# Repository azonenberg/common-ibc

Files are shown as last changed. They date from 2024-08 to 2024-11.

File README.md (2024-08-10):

# common-ibc

This is a 48-12V 72W non-isolated intermediate bus converter which I plan to use in all of my larger FPGA projects.

It uses a charge pump which has a fixed divide-by-4 output ratio rather than using a regulating buck topology. This
allows high efficiency but requires downstream loads to be able to tolerate a wider range of input voltages.

The architecture is scalable to 2 or 4 parallel converter modules, allowing 144W (12A) or 288W (24A) IBCs based on the
same chipset to be constructed in a straightforward manner based on a scaling of this design, however there are no
near-term plans to create such a converter since none of my near term project plans require that much power.

## Input

The input is +48VDC nominal on a 6-pin Molex Mini-Fit Jr connector, using a pinout compatible with the Mean Well
GST280A48-C6P power brick (and possibly others). The negative terminal of the input power connection is connected to
circuit ground.

The permissible operating range is 40 to 56VDC (corresponding to 10 to 14V output). An input protection circuit will
disable the converter if the input is out of this range.

The unregulated output voltage is 1/4 of the input, so if the load has tighter requirements for accuracy of the 12V
rail then this will further constrain the input supply voltage.

## Internal Construction

The converter is built around the Murata MYC0409-NA charge pump DC-DC module.

## Outputs

In addition to the high current 12V output (on an 8-pin Molex Mini-Fit Jr connector) the converter provides a 3.3V
standby rail (using the Cyntec MUN12AD03-SE regulating off of the 12V rail), capable of up to 3A, which is intended for
powering sleep/idle circuitry such as soft power on/off, rail sequencing, etc.

Both the primary 12V step-down converter and the 3.3V standby regulator are always enabled, however a load switch on
the main 12V output allows it to be disabled to completely power down the bulk of the downstream device, keeping only
the converter board and the 3V3_SB rail on the downstream device energized. The load switch has an integrated soft
start, preventing high current surges when charging bulk capacitance on the load.

## Monitoring

The onboard STM32L431 microcontroller monitors the PGOOD signals of internal regulators as well as the ALERT output
of the onboard AT30TS74 temperature sensor. It also continually uses an internal ADC to record the input and output
voltage, downstream load sense voltage, and input and output current. All of these sensor readings may be queried by
the load over the I2C management bus.

## Protection

The converter includes multiple levels of protection to minimize the risk of fire or equipment damage.

The most critical interlocks are implemented in hardware while additional protections with lower thresholds are
implemented in software on the management MCU.

If a software interlock triggers, the 12V output is disabled. The management MCU will automatically attempt to restart
the output (as long as the load is still requesting power) at periodic intervals once the fault condition is cleared.

The 3.3V standby output will remain active and the management MCU will remain operational while a software interlock is
tripped.

### Input overcurrent

The 48V input is fused at 2.5A using a socketed 5x20mm fast-blow fuse.

### Output overcurrent

The 12V primary output is fused at 10A using a soldered-down fast-blow fuse.

The 3.3V standby output is current limited (typical range 3.8 - 5.2A) by the DC-DC converter and does not have an
supplemental fuse.

If the 12V output current exceeds 6.5A, a software interlock is triggered. The output load switch also has a
short circuit protection feature, however the software interlock is intended to trip at a lower level.

### Regulator fault

If any of the internal regulators indicates a problem (PGOOD low) a software interlock is triggered.

### Over-temperature

If the AT30TS74 indicates an out-of-bounds temperature (ALERT low) a software interlock is triggered.

The MCU does not configure the AT30TS74; on power up the default over-temperature limit (80C) is active. This sensor is
located on the same I2C management bus as the MCU and may be reconfigured or queried by the load as required; the
IBC will activate the interlock if the programmed temperature range is exceeded.

### Input under / over voltage

The input is monitored by a TPS16630 protection controller, which also provides soft-start for the input bulk
capacitance. If the input voltage drops below 40V or rises above 56V (corresponding to 10-14V output) the system will
shut down completely (input power cut off upstream of the charge pump, disabling the microcontroller, 3.3V standby
rail, and all internal circuitry past the protection controller).

The input has a Schottky diode to ground in reverse polarity. If the input goes significantly negative (reverse
polarity connection) the diode will conduct and blow the input fuse, hopefully protecting the load and possibly even
the power supply from damage.

As an additional protection against catastrophic overvoltage at the input, a zener clamp will trip at approximately
58V, blowing the input fuse.

### Output under / over voltage

Since the output voltage is normally a fixed 4:1 scaling of the input, output voltage drifting beyond this range is
likely indicative of a failure of the charge pump module.

* If the 12V rail voltage drops below 10V, a software interlock is triggered.
* If the 12V rail voltage rises above 14V, a software interlock is triggered.
* If the 12V rail voltage rises above 17V a zener clamp on the output will begin to conduct, blowing the output fuse.

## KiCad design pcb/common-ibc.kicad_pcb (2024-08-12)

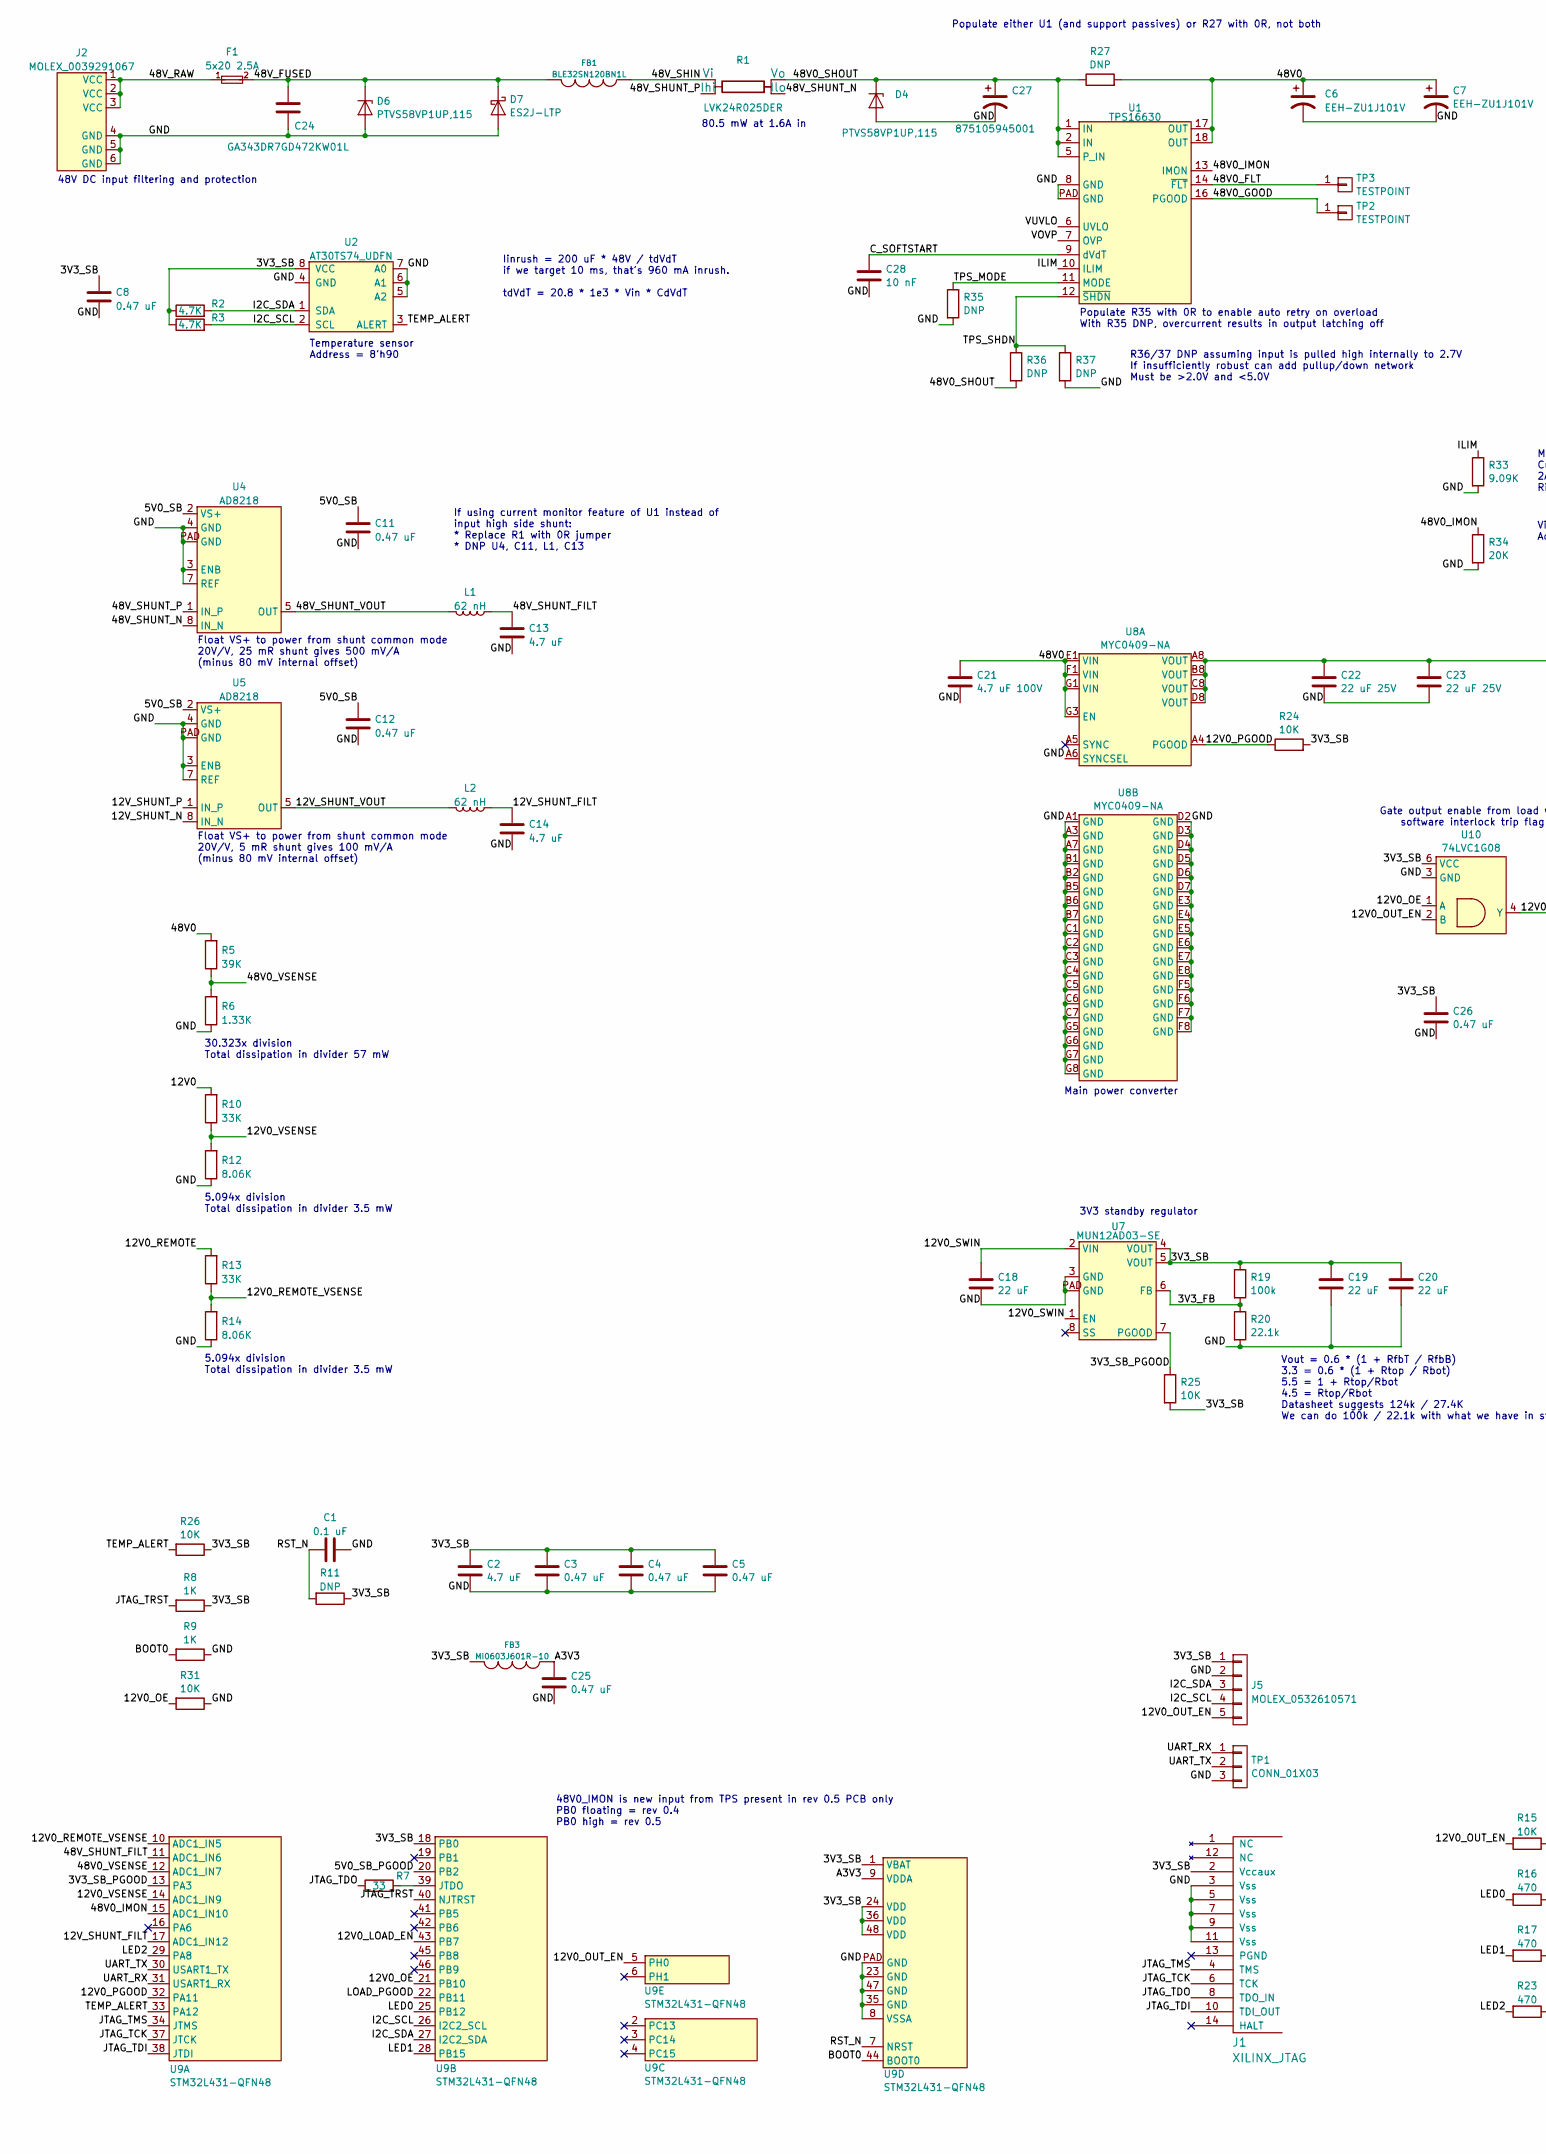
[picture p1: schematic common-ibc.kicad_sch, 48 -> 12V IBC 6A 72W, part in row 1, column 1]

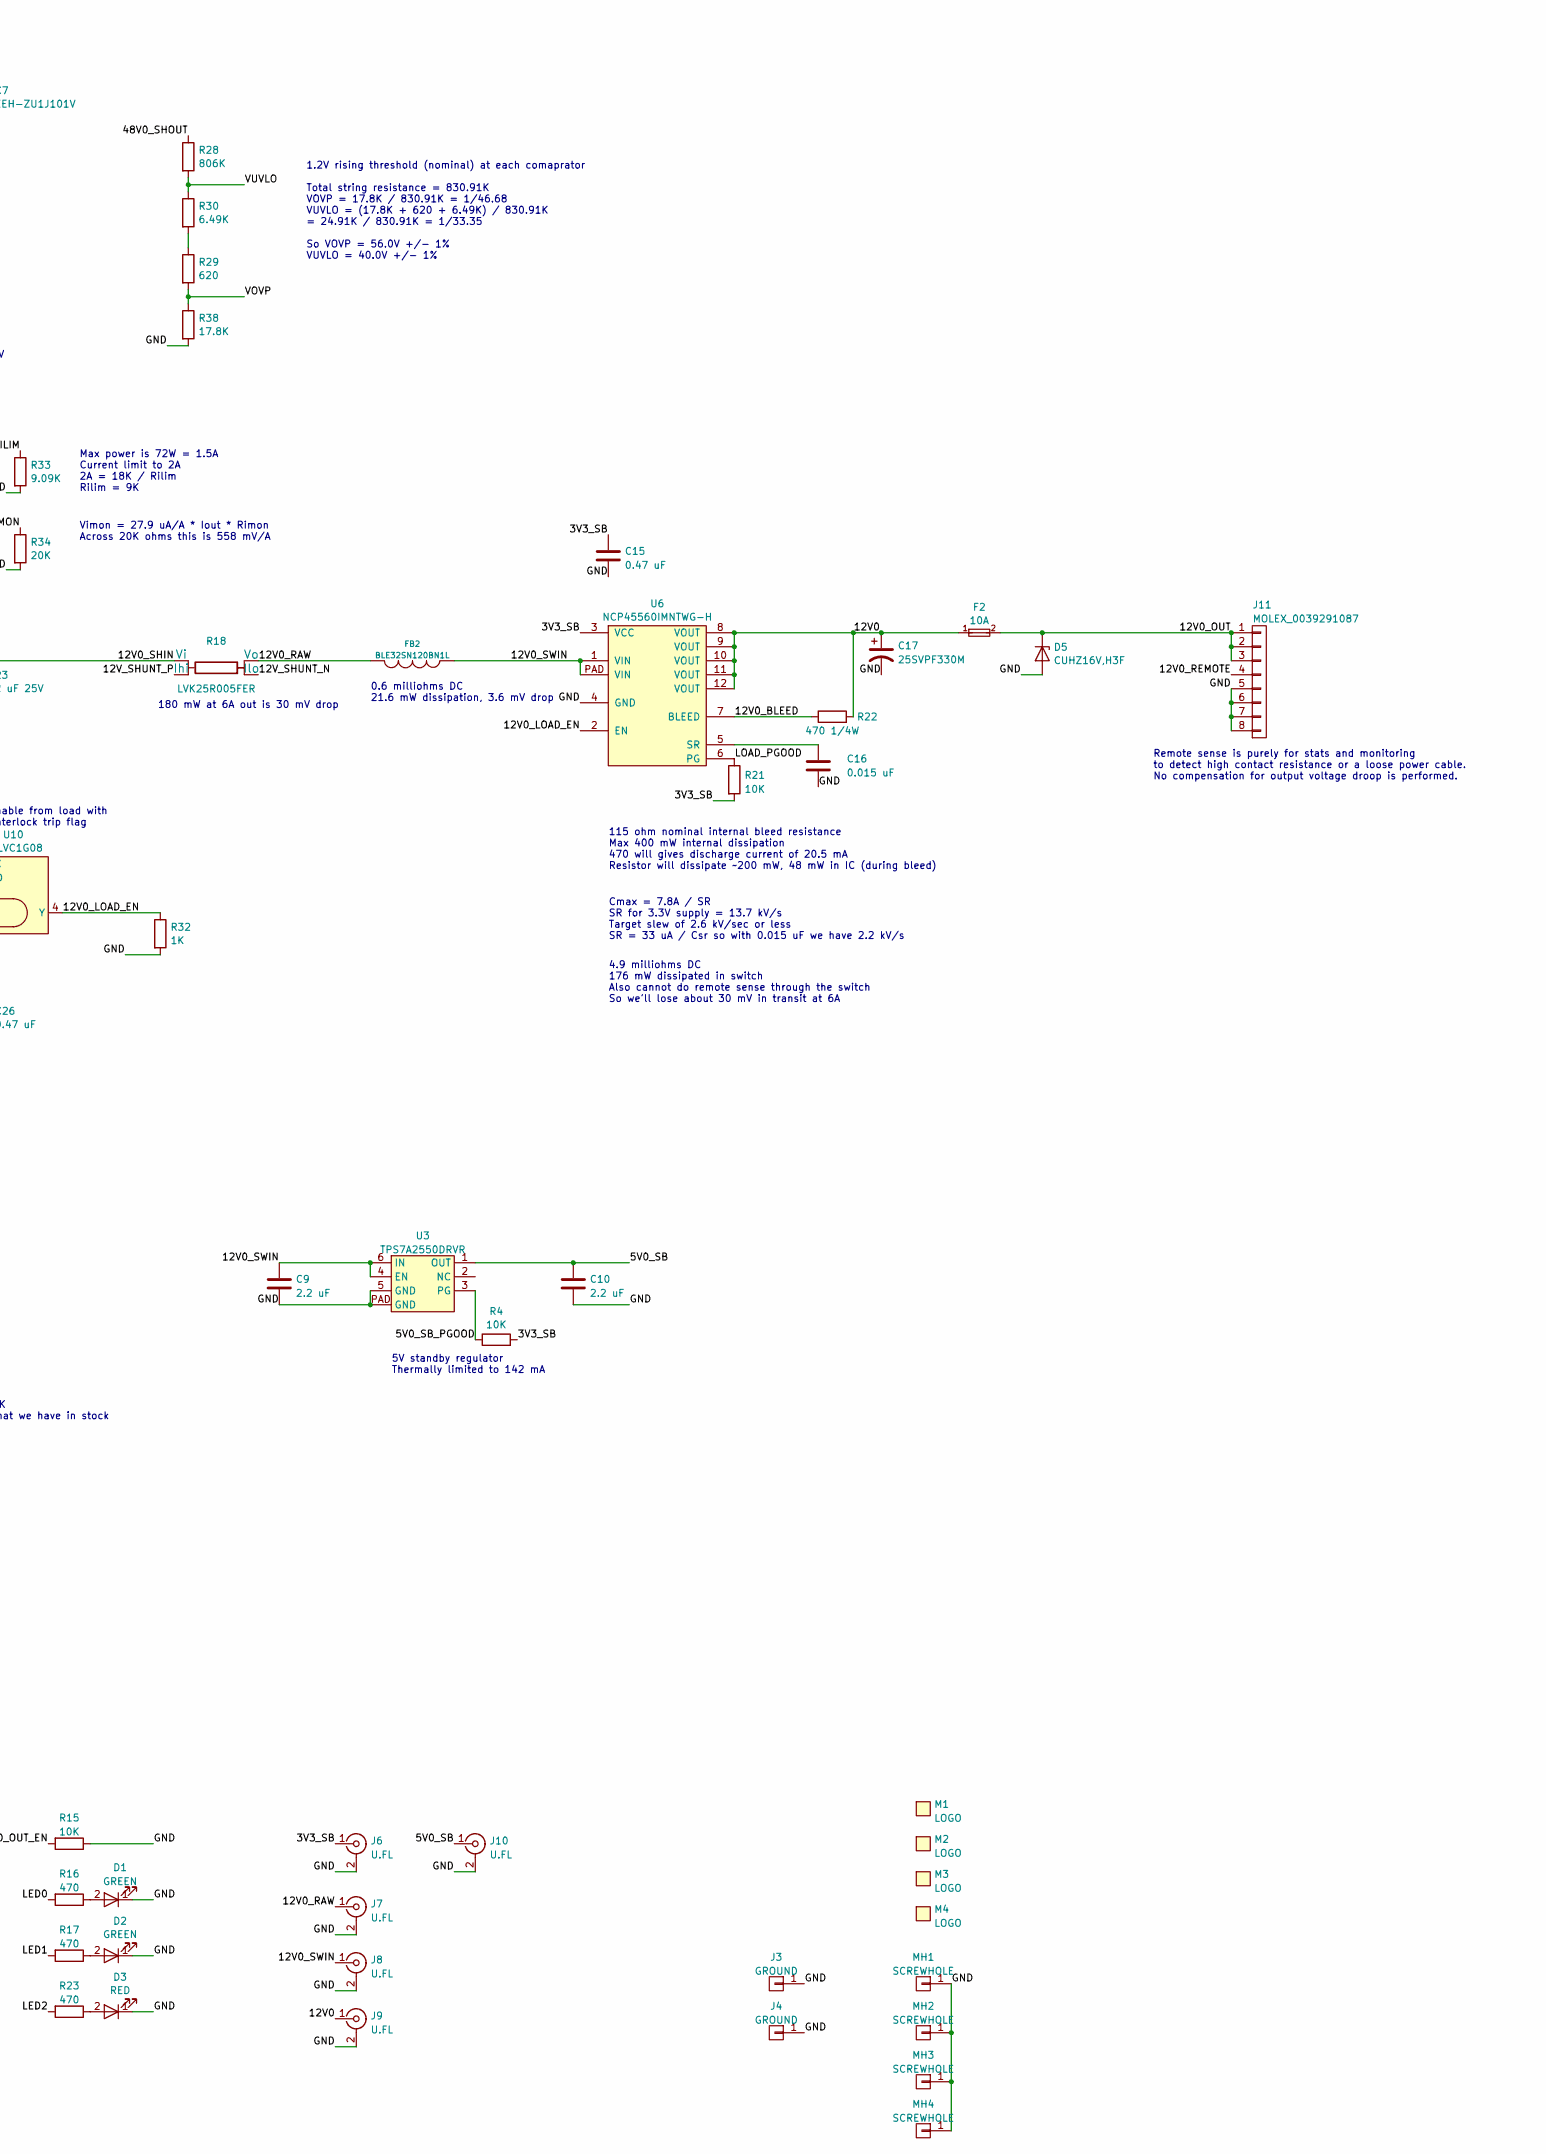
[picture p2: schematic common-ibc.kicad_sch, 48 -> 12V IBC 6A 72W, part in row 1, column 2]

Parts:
C1: 0.1 uF; EIA_0402_CAP_NOSILK
C2, C13, C14: 4.7 uF; EIA_0603_CAP_NOSILK
C3, C4, C5, C8, C11, C12, C15, C25, C26: 0.47 uF; EIA_0402_CAP_NOSILK
C6, C7: EEH-ZU1J101V; CAP_AL_10MM_SMT
C9, C10: 2.2 uF; EIA_0805_CAP_NOSILK
C16: 0.015 uF; EIA_0603_CAP_NOSILK
C17: 25SVPF330M; CAP_AL_10MM_SMT
C18: 22 uF; EIA_1812_CAP_NOSILK
C19, C20: 22 uF; EIA_1210_CAP_NOSILK
C21: 4.7 uF 100V; CAP_TDK_CKG57K
C22, C23: 22 uF 25V; EIA_1812_CAP_NOSILK
C24: GA343DR7GD472KW01L; EIA_1812_CAP_NOSILK
C27: 875105945001; CAP_AL_6.3MM_SMT
C28: 10 nF; EIA_0402_CAP_NOSILK
D1, D2: GREEN; EIA_0603_LED
D3: RED; EIA_0603_LED
D4, D6: PTVS58VP1UP,115; SOD128
D5: CUHZ16V,H3F; SOD323H
D7: ES2J-LTP; SMA
F1: 5x20 2.5A; FUSEHOLDER_KEYSTONE_4527
F2: 10A; EIA_1206_FUSE_NOSILK
FB1, FB2: BLE32SN120BN1L; EIA_1210_CAP_NOSILK
FB3: MI0603J601R-10; EIA_0603_INDUCTOR_NOSILK
J1: XILINX_JTAG; XILINX_JTAG_PTH_MOLEX_0878311420
J2: MOLEX_0039291067; CONN_MOLEX_MINIFITJR_6POS_0039291067
J3, J4: GROUND; TESTPOINT_SMT_KEYSTONE_5016
J5: MOLEX_0532610571; CONN_MOLEX_PICOBLADE_5POS_0532610571
J6, J7, J8, J9, J10: U.FL; CONN_U.FL_TE_1909763-1
J11: MOLEX_0039291087; CONN_MOLEX_MINIFITJR_8POS_0039291087
L1, L2: 62 nH; EIA_0402_CAP_NOSILK
M1: LOGO; LONGTHING-1200DPI
M2: LOGO; Logo_silk_OSHW_6x6mm
M3: LOGO; Logo_silk_ROHS_5x2.8mm
M4: LOGO; Logo_silk_WEEE_3.4x5mm
MH1, MH2, MH3, MH4: SCREWHOLE; MECHANICAL_CLEARANCEHOLE_4_40
R1: LVK24R025DER; OHMITE_LVK24
R2, R3: 4.7K; EIA_0402_RES_NOSILK
R4, R15, R21, R24, R25, R26, R31: 10K; EIA_0402_RES_NOSILK
R5: 39K; EIA_0402_RES_NOSILK
R6: 1.33K; EIA_0402_RES_NOSILK
R7: 33; EIA_0402_RES_NOSILK
R8, R9, R32: 1K; EIA_0402_RES_NOSILK
R10, R13: 33K; EIA_0402_RES_NOSILK
R11, R35, R37: DNP; EIA_0402_RES_NOSILK
R12, R14: 8.06K; EIA_0402_RES_NOSILK
R16, R17, R23: 470; EIA_0402_RES_NOSILK
R18: LVK25R005FER; OHMITE_LVK25
R19: 100k; EIA_0402_RES_NOSILK
R20: 22.1k; EIA_0402_RES_NOSILK
R22: 470 1/4W; EIA_0603_RES_NOSILK
R27: DNP; EIA_0805_CAP_NOSILK
R28: 806K; EIA_0603_RES_NOSILK
R29: 620; EIA_0402_RES_NOSILK
R30: 6.49K; EIA_0402_RES_NOSILK
R33: 9.09K; EIA_0402_RES_NOSILK
R34: 20K; EIA_0402_RES_NOSILK
R36: DNP; EIA_0603_RES_NOSILK
R38: 17.8K; EIA_0402_RES_NOSILK
TP1: CONN_01X03; CONN_HEADER_2.54MM_1x3
TP2, TP3: TESTPOINT; TESTPOINT_SMT_0.5MM
U1: TPS16630; QFN_24_0.5MM_4x4MM
U2: AT30TS74_UDFN; DFN_8_0.5MM_2x3MM_TALL
U3: TPS7A2550DRVR; DFN_6_0.65MM_2x2MM
U4, U5: AD8218; DFN_8_0.5MM_2x3MM_TALL
U6: NCP45560IMNTWG-H; DFN_12_0.5MM_3x3MM
U7: MUN12AD03-SE; MODULE_CYNTEC_MUN12AD03-SE
U8: MYC0409-NA; MODULE_MURATA_MYC0409-NA
U9: STM32L431-QFN48; QFN_48_0.5MM_7x7MM
U10: 74LVC1G08; DFN_6_0.5MM_1.4x1.00MM_NXP_X2-DFN1410-6

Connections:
/3V3_FB: R19.2, R20.1, U7.6 (FB)
/3V3_SB: C2.1, C3.1, C4.1, C5.1, C8.1, C15.1, C19.1, C20.1, C26.1, FB3.2, J1.2 (Vccaux), J5.1, J6.1 (In), R2.1, R3.1, R4.2, R8.1, R11.1, R19.1, R21.2, R24.2, R25.2, R26.1, U2.8 (VCC), U6.3 (VCC), U7.4 (VOUT), U7.5 (VOUT), U9.1 (VBAT), U9.18 (PB0), U9.24 (VDD), U9.36 (VDD), U9.48 (VDD), U10.6 (VCC)
/3V3_SB_PGOOD: R25.1, U7.7 (PGOOD), U9.13 (PA3)
/5V0_SB: C10.1, C11.1, C12.1, J10.1 (In), U3.1 (OUT), U4.2 (VS+), U5.2 (VS+)
/5V0_SB_PGOOD: R4.1, U3.3 (PG), U9.20 (PB2)
/12V0: C17.1, F2.1, J9.1 (In), R10.2, R22.2, U6.8 (VOUT), U6.9 (VOUT), U6.10 (VOUT), U6.11 (VOUT), U6.12 (VOUT)
/12V0_BLEED: R22.1, U6.7 (BLEED)
/12V0_LOAD_EN: R32.1, U6.2 (EN), U9.43 (PB7), U10.4 (Y)
/12V0_OE: R31.2, U9.21 (PB10), U10.1 (A)
/12V0_OUT: D5.1 (K), F2.2, J11.1, J11.2, J11.3
/12V0_OUT_EN: J5.5, R15.2, U9.5 (PH0), U10.2 (B)
/12V0_PGOOD: R24.1, U8.A4 (PGOOD), U9.32 (PA11)
/12V0_RAW: FB2.2, J7.1 (In), R18.2 (Vo)
/12V0_REMOTE: J11.4, R13.2
/12V0_REMOTE_VSENSE: R13.1, R14.2, U9.10 (ADC1_IN5)
/12V0_SHIN: C22.1, C23.1, R18.4 (Vi), U8.A8 (VOUT), U8.B8 (VOUT), U8.C8 (VOUT), U8.D8 (VOUT)
/12V0_SWIN: C9.1, C18.1, FB2.1, J8.1 (In), U3.4 (EN), U3.6 (IN), U6.1 (VIN), U6.PAD (VIN), U7.1 (EN), U7.2 (VIN)
/12V0_VSENSE: R10.1, R12.2, U9.14 (ADC1_IN9)
/12V_SHUNT_FILT: C14.2, L2.1, U9.17 (ADC1_IN12)
/12V_SHUNT_N: R18.1 (Ilo), U5.8 (IN_N)
/12V_SHUNT_P: R18.3 (Ihi), U5.1 (IN_P)
/12V_SHUNT_VOUT: L2.2, U5.5 (OUT)
/48V0: C6.1, C7.1, C21.1, R5.2, R27.2, U1.17 (OUT), U1.18 (OUT), U8.E1 (VIN), U8.F1 (VIN), U8.G1 (VIN), U8.G3 (EN)
/48V0_FLT: TP3.1, U1.14 (~FLT)
/48V0_GOOD: TP2.1, U1.16 (PGOOD)
/48V0_IMON: R34.1, U1.13 (IMON), U9.15 (ADC1_IN10)
/48V0_SHOUT: C27.1, D4.1 (K), R1.2 (Vo), R27.1, R28.1, R36.2, U1.1 (IN), U1.2 (IN), U1.5 (P_IN)
/48V0_VSENSE: R5.1, R6.2, U9.12 (ADC1_IN7)
/48V_FUSED: C24.1, D6.1 (K), D7.1 (K), F1.2, FB1.2
/48V_RAW: F1.1, J2.1 (VCC), J2.2 (VCC), J2.3 (VCC)
/48V_SHIN: FB1.1, R1.4 (Vi)
/48V_SHUNT_FILT: C13.2, L1.1, U9.11 (ADC1_IN6)
/48V_SHUNT_N: R1.1 (Ilo), U4.8 (IN_N)
/48V_SHUNT_P: R1.3 (Ihi), U4.1 (IN_P)
/48V_SHUNT_VOUT: L1.2, U4.5 (OUT)
/A3V3: C25.1, FB3.1, U9.9 (VDDA)
/BOOT0: R9.2, U9.44 (BOOT0)
/C_SOFTSTART: C28.1, U1.9 (dVdT)
/GND: C1.2, C2.2, C3.2, C4.2, C5.2, C6.2, C7.2, C8.2, C9.2, C10.2, C11.2, C12.2, C13.1, C14.1, C15.2, C16.2, C17.2, C18.2, C19.2, C20.2, C21.2, C22.2, C23.2, C24.2, C25.2, C26.2, C27.2, C28.2, D1.1 (K), D2.1 (K), D3.1 (K), D4.2 (A), D5.2 (A), D6.2 (A), D7.2 (A), J1.3 (Vss), J1.5 (Vss), J1.7 (Vss), J1.9 (Vss), J1.11 (Vss), J2.4 (GND), J2.5 (GND), J2.6 (GND), J3.1, J4.1, J5.2, J6.2 (Ext), J7.2 (Ext), J8.2 (Ext), J9.2 (Ext), J10.2 (Ext), J11.5, J11.6, J11.7, J11.8, MH1.1, MH2.1, MH3.1, MH4.1, R6.1, R9.1, R12.1, R14.1, R15.1, R20.2, R31.1, R32.2, R33.2, R34.2, R35.2, R37.2, R38.2, TP1.3, U1.8 (GND), U1.PAD (GND), U2.4 (GND), U2.5 (A2), U2.6 (A1), U2.7 (A0), U3.5 (GND), U3.PAD (GND), U4.3 (ENB), U4.4 (GND), U4.7 (REF), U4.PAD (GND), U5.3 (ENB), U5.4 (GND), U5.7 (REF), U5.PAD (GND), U6.4 (GND), U7.3 (GND), U7.PAD (GND), U8.A1 (GND), U8.A3 (GND), U8.A6 (SYNCSEL), U8.A7 (GND), U8.B1 (GND), U8.B2 (GND), U8.B5 (GND), U8.B6 (GND), U8.B7 (GND), U8.C1 (GND), U8.C2 (GND), U8.C3 (GND), U8.C4 (GND), U8.C5 (GND), U8.C6 (GND), U8.C7 (GND), U8.D2 (GND), U8.D3 (GND), U8.D4 (GND), U8.D5 (GND), U8.D6 (GND), U8.D7 (GND), U8.E3 (GND), U8.E4 (GND), U8.E5 (GND), U8.E6 (GND), U8.E7 (GND), U8.E8 (GND), U8.F5 (GND), U8.F6 (GND), U8.F7 (GND), U8.F8 (GND), U8.G5 (GND), U8.G6 (GND), U8.G7 (GND), U8.G8 (GND), U9.8 (VSSA), U9.23 (GND), U9.35 (GND), U9.47 (GND), U9.PAD (GND), U10.3 (GND)
/I2C_SCL: J5.4, R3.2, U2.2 (SCL), U9.26 (I2C2_SCL)
/I2C_SDA: J5.3, R2.2, U2.1 (SDA), U9.27 (I2C2_SDA)
/ILIM: R33.1, U1.10 (ILIM)
/JTAG_TCK: J1.6 (TCK), U9.37 (JTCK)
/JTAG_TDI: J1.10 (TDI_OUT), U9.38 (JTDI)
/JTAG_TDO: J1.8 (TDO_IN), R7.1
/JTAG_TMS: J1.4 (TMS), U9.34 (JTMS)
/JTAG_TRST: R8.2, U9.40 (NJTRST)
/LED0: R16.2, U9.25 (PB12)
/LED1: R17.2, U9.28 (PB15)
/LED2: R23.2, U9.29 (PA8)
/LOAD_PGOOD: R21.1, U6.6 (PG), U9.22 (PB11)
/RST_N: C1.1, R11.2, U9.7 (NRST)
/TEMP_ALERT: R26.2, U2.3 (ALERT), U9.33 (PA12)
/TPS_MODE: R35.1, U1.11 (MODE)
/TPS_SHDN: R36.1, R37.1, U1.12 (~SHDN)
/UART_RX: TP1.1, U9.31 (USART1_RX)
/UART_TX: TP1.2, U9.30 (USART1_TX)
/VOVP: R29.2, R38.1, U1.7 (OVP)
/VUVLO: R28.2, R30.1, U1.6 (UVLO)
unnamed: D1.2 (A), R16.1
unnamed: D2.2 (A), R17.1
unnamed: D3.2 (A), R23.1
unnamed: R29.1, R30.2
unnamed: C16.1, U6.5 (SR)
unnamed: R7.2, U9.39 (JTDO)

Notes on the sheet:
80.5 mW at 1.6A in
Populate R35 with 0R to enable auto retry on overload With R35 DNP, overcurrent results in output latching off
115 ohm nominal internal bleed resistance Max 400 mW internal dissipation 470 will gives discharge current of 20.5 mA Resistor will dissipate ~200 mW, 48 mW in IC (during bleed)
1.2V rising threshold (nominal) at each comaprator Total string resistance = 830.91K VOVP = 17.8K / 830.91K = 1/46.68 VUVLO = (17.8K + 620 + 6.49K) / 830.91K = 24.91K / 830.91K = 1/33.35 So VOVP = 56.0V +/- 1% VUVLO = 40.0V +/- 1%
Iinrush = 200 uF * 48V / tdVdT if we target 10 ms, that's 960 mA inrush. tdVdT = 20.8 * 1e3 * Vin * CdVdT
Max power is 72W = 1.5A Current limit to 2A 2A = 18K / Rilim Rilim = 9K
Populate either U1 (and support passives) or R27 with 0R, not both
5V standby regulator Thermally limited to 142 mA
Vout = 0.6 * (1 + RfbT / RfbB) 3.3 = 0.6 * (1 + Rtop / Rbot) 5.5 = 1 + Rtop/Rbot 4.5 = Rtop/Rbot Datasheet suggests 124k / 27.4K We can do 100k / 22.1k with what we have in stock
48V0_IMON is new input from TPS present in rev 0.5 PCB only PB0 floating = rev 0.4 PB0 high = rev 0.5
180 mW at 6A out is 30 mV drop
30.323x division Total dissipation in divider 57 mW
Vimon = 27.9 uA/A * Iout * Rimon Across 20K ohms this is 558 mV/A
Temperature sensor Address = 8'h90
Float VS+ to power from shunt common mode 20V/V, 5 mR shunt gives 100 mV/A (minus 80 mV internal offset)
If using current monitor feature of U1 instead of input high side shunt: * Replace R1 with 0R jumper * DNP U4, C11, L1, C13
Float VS+ to power from shunt common mode 20V/V, 25 mR shunt gives 500 mV/A (minus 80 mV internal offset)
R36/37 DNP assuming input is pulled high internally to 2.7V If insufficiently robust can add pullup/down network Must be >2.0V and <5.0V
0.6 milliohms DC 21.6 mW dissipation, 3.6 mV drop
Cmax = 7.8A / SR SR for 3.3V supply = 13.7 kV/s Target slew of 2.6 kV/sec or less SR = 33 uA / Csr so with 0.015 uF we have 2.2 kV/s
Remote sense is purely for stats and monitoring to detect high contact resistance or a loose power cable. No compensation for output voltage droop is performed.
3V3 standby regulator
Gate output enable from load with software interlock trip flag
5.094x division Total dissipation in divider 3.5 mW
Main power converter
4.9 milliohms DC 176 mW dissipated in switch Also cannot do remote sense through the switch So we'll lose about 30 mV in transit at 6A
48V DC input filtering and protection

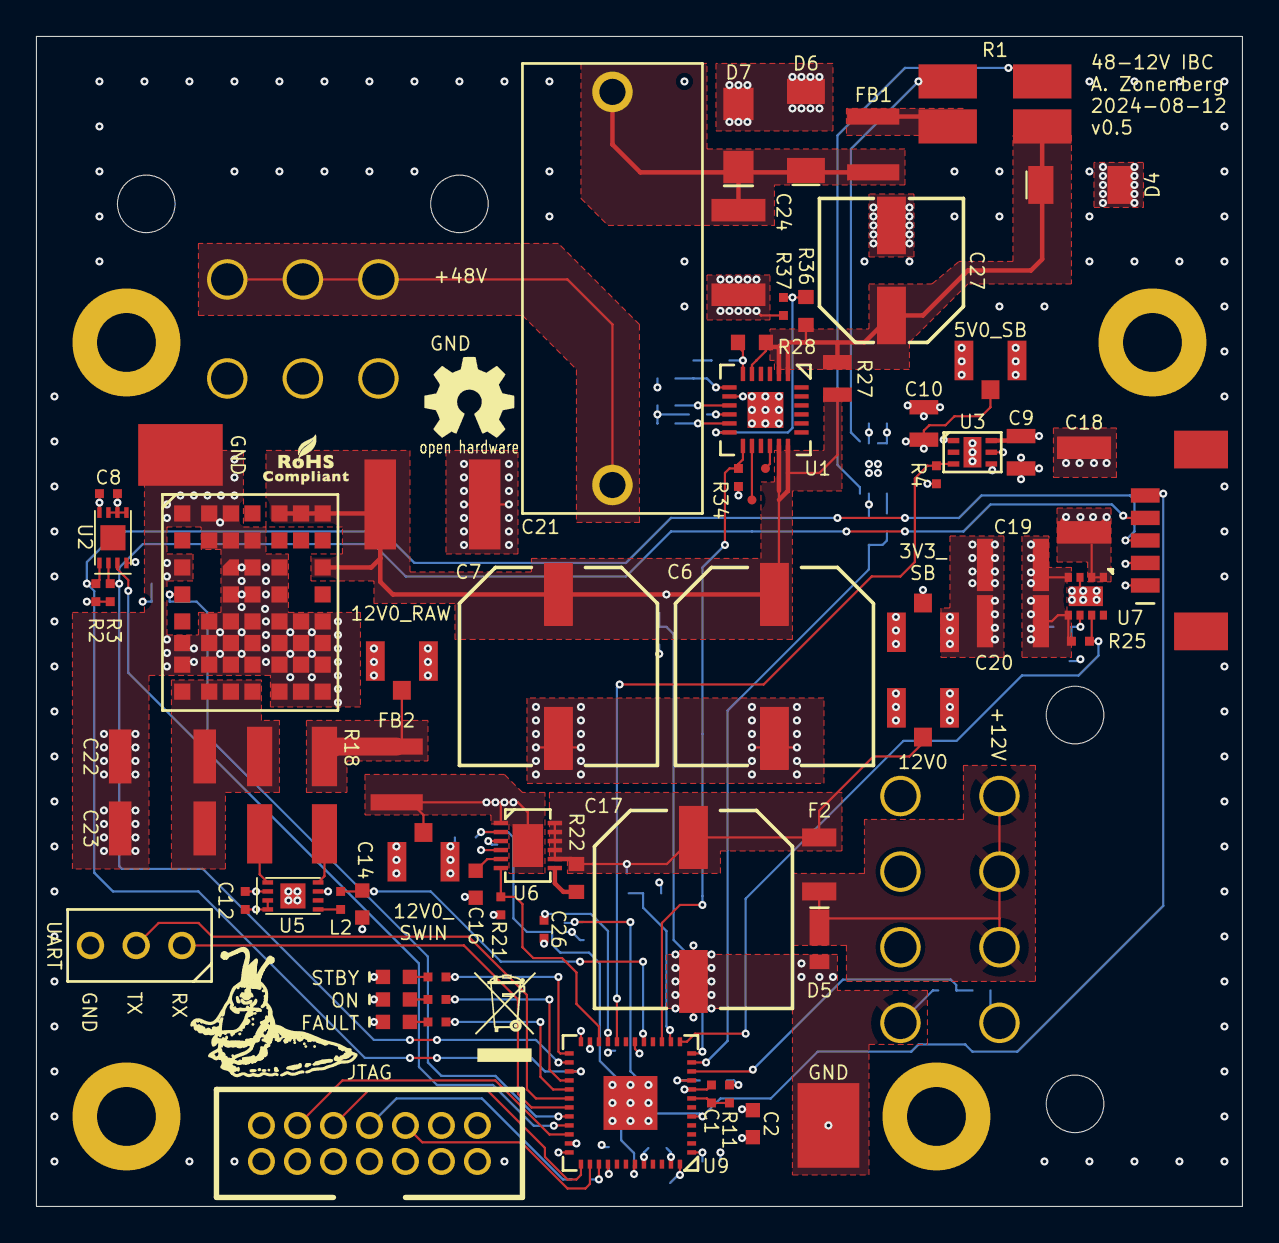
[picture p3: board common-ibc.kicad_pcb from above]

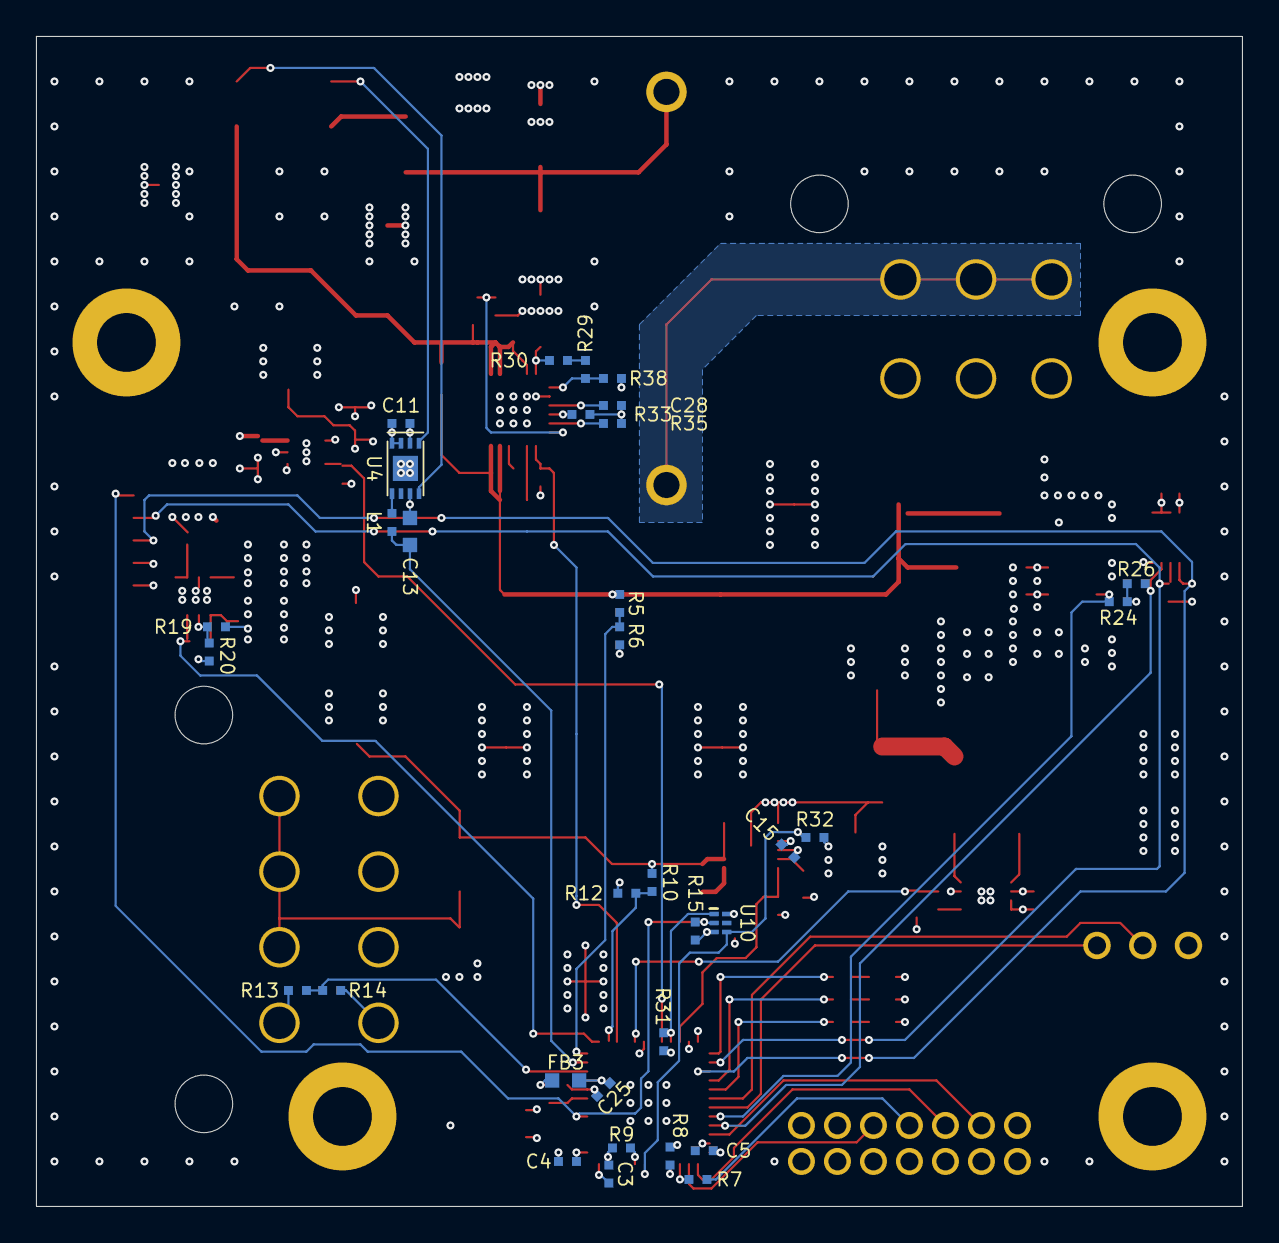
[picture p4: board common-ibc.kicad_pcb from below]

Board: 4 copper layers, 67.0 x 65.0 mm, 112 parts (33 on the bottom side), 65 nets.

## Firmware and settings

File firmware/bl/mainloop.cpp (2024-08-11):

/***********************************************************************************************************************
*                                                                                                                      *
* common-ibc                                                                                                           *
*                                                                                                                      *
* Copyright (c) 2024 Andrew D. Zonenberg and contributors                                                              *
* All rights reserved.                                                                                                 *
*                                                                                                                      *
* Redistribution and use in source and binary forms, with or without modification, are permitted provided that the     *
* following conditions are met:                                                                                        *
*                                                                                                                      *
*    * Redistributions of source code must retain the above copyright notice, this list of conditions, and the         *
*      following disclaimer.                                                                                           *
*                                                                                                                      *
*    * Redistributions in binary form must reproduce the above copyright notice, this list of conditions and the       *
*      following disclaimer in the documentation and/or other materials provided with the distribution.                *
*                                                                                                                      *
*    * Neither the name of the author nor the names of any contributors may be used to endorse or promote products     *
*      derived from this software without specific prior written permission.                                           *
*                                                                                                                      *
* THIS SOFTWARE IS PROVIDED BY THE AUTHORS "AS IS" AND ANY EXPRESS OR IMPLIED WARRANTIES, INCLUDING, BUT NOT LIMITED   *
* TO, THE IMPLIED WARRANTIES OF MERCHANTABILITY AND FITNESS FOR A PARTICULAR PURPOSE ARE DISCLAIMED. IN NO EVENT SHALL *
* THE AUTHORS BE HELD LIABLE FOR ANY DIRECT, INDIRECT, INCIDENTAL, SPECIAL, EXEMPLARY, OR CONSEQUENTIAL DAMAGES        *
* (INCLUDING, BUT NOT LIMITED TO, PROCUREMENT OF SUBSTITUTE GOODS OR SERVICES; LOSS OF USE, DATA, OR PROFITS; OR       *
* BUSINESS INTERRUPTION) HOWEVER CAUSED AND ON ANY THEORY OF LIABILITY, WHETHER IN CONTRACT, STRICT LIABILITY, OR TORT *
* (INCLUDING NEGLIGENCE OR OTHERWISE) ARISING IN ANY WAY OUT OF THE USE OF THIS SOFTWARE, EVEN IF ADVISED OF THE       *
* POSSIBILITY OF SUCH DAMAGE.                                                                                          *
*                                                                                                                      *
***********************************************************************************************************************/

#include <core/platform.h>
#include <bootloader/bootloader-common.h>
#include <bootloader/BootloaderAPI.h>
#include <algorithm>
#include "../bsp/hwinit.h"

//Application region of flash runs from the end of the bootloader (0x08008000)
//to the start of the KVS (0x0803f000), so 220 kB
//Firmware version string is put right after vector table by linker script at a constant address
uint32_t* const g_appVector  = reinterpret_cast<uint32_t*>(0x8008000);

//@brief Size of the image
const uint32_t g_appImageSize = 220 * 1024;

//Offset of the version string
const uint32_t g_appVersionOffset = 0x1a0;

////////////////////////////////////////////////////////////////////////////////////////////////////////////////////////
// Hooks called by bootloader code

void Bootloader_Init()
{

}

void Bootloader_ClearRxBuffer()
{
}

void Bootloader_FinalCleanup()
{
	g_uart.Flush();
}

void BSP_MainLoop()
{
	Bootloader_MainLoop();
}

////////////////////////////////////////////////////////////////////////////////////////////////////////////////////////
// Run the firmware updater

void __attribute__((noreturn)) Bootloader_FirmwareUpdateFlow()
{
	g_log("In DFU mode\n");
	/*
	uint32_t nbyte = 0;
	uint8_t cmd = 0;

	CircularFIFO<2048> writebuf;
	uint32_t wraddr = 0;
	uint32_t wraddrNext = 0;
	uint32_t bytesSoFar = 0;
	uint32_t bytesLastPrinted = 0;
	uint32_t expectedCRC = 0;
	*/
	while(1)
	{
		g_log.UpdateOffset(60000);
		/*
		//If we have at least a full 8-byte block of data, push it to flash
		if(cmd != FRONT_FLASH_WRITE)
		{
			while(writebuf.ReadSize() >= 8)
			{
				Flash::Write((uint8_t*)wraddr, writebuf.Rewind(), 8);
				writebuf.Pop(8);
				wraddr += 8;
				bytesSoFar += 8;

				if(bytesSoFar > (bytesLastPrinted + 4096))
				{
					g_log("[%08x] Wrote %d bytes, %u still in buffer, %u overflows, %u pending\n",
						wraddr, bytesSoFar, writebuf.ReadSize(), g_spiRxFifoOverflows, g_fpgaSPI.GetEventCount());
					bytesLastPrinted = bytesSoFar;
				}

				//If there's <8 bytes left and we're not still pushing new data, we're done
				if( (writebuf.ReadSize() < 8) && (cmd != FRONT_FLASH_WRITE) )
				{
					g_fpgaSPI.NonblockingWriteDevice(0x01);
					break;
				}
			}
		}

		//If CS# deasserted, go to JTAG mode
		if(*g_fpgaSPICS)
		{
			if(!g_misoIsJtag)
				SetMisoToJTAGMode();
		}

		//Read and process SPI events
		if(g_fpgaSPI.HasEvents())
		{
			auto event = g_fpgaSPI.GetEvent();

			//Reset byte count on CS# rising or falling edge
			if(event.type == SPIEvent::TYPE_CS)
				nbyte = 0;

			//Process data byte
			else
			{
				auto data = event.data;

				//First byte is command
				if(nbyte == 0)
				{
					cmd = data;

					switch(cmd)
					{
						//padding sent during flash writes etc, discard it
						case 0x00:
							break;

						//Update write address but account for pending data not yet written
						case FRONT_FLASH_WRITE:
							wraddr = wraddrNext - writebuf.ReadSize();
							break;

						//Launch the application
						case FRONT_BOOT_APP:
							{
								g_log("Preparing to boot application\n");

								auto sver = GetImageVersion(g_appVector);
								if(!sver)
								{
									g_log(Logger::ERROR, "No image version string found\n");
									continue;
								}

								//Write image version and expected CRC to KVS
								g_kvs->StoreObject(g_imageVersionKey, (const uint8_t*)sver, strlen(sver));
								g_kvs->StoreObject(g_imageCRCKey, (const uint8_t*)&expectedCRC, sizeof(uint32_t));

								//Try booting it
								if(ValidateAppPartition(g_appVector))
									BootApplication(g_appVector);
								g_log("Image is invalid, remaining in DFU mode\n");
							}
							break;

						//Start erasing flash
						case FRONT_ERASE_APP:

							//Tell client we're busy
							if(g_misoIsJtag)
								SetMisoToSPIMode();
							g_fpgaSPI.NonblockingWriteDevice(0x00);

							//Do the erase cycle
							bytesSoFar = 0;
							bytesLastPrinted = 0;
							expectedCRC = 0;
							EraseFlash(g_appVector);

							//Discard any SPI data events that showed up during erase
							g_fpgaSPI.ClearEvents();

							//We're now done
							g_fpgaSPI.NonblockingWriteDevice(0x01);

							break;

						//Get the operating mode
						case FRONT_GET_STATUS:
							{
								if(g_misoIsJtag)
									SetMisoToSPIMode();

								g_fpgaSPI.NonblockingWriteDevice(FRONT_BOOTLOADER);
							}
							break;

						//Get write status
						case FRONT_FLASH_STATUS:

							//Tell client we're busy
							if(g_misoIsJtag)
								SetMisoToSPIMode();
							g_fpgaSPI.NonblockingWriteDevice(0x00);

							break;

						//Synchronize to make sure we're not reading stale data
						case FRONT_FLASH_SYNC:

							//Tell client we're busy
							if(g_misoIsJtag)
								SetMisoToSPIMode();
							g_fpgaSPI.NonblockingWriteDevice(0xcc);

							break;

						//Flush any remaining flash data (end of the block)
						case FRONT_FLASH_FLUSH:
							{
								//Tell client we're busy
								if(g_misoIsJtag)
									SetMisoToSPIMode();
								g_fpgaSPI.NonblockingWriteDevice(0x00);

								//Flush any remaining data to flash
								auto nbytes = writebuf.ReadSize();
								if(nbytes > 0)
								{
									Flash::Write((uint8_t*)wraddr, writebuf.Rewind(), nbytes);
									writebuf.Pop(nbytes);
									wraddr += nbytes;
								}

								g_log("Flushed write buffer, total %u bytes so far\n", bytesSoFar);

								//We're now done
								g_fpgaSPI.NonblockingWriteDevice(0x01);
							}
							break;

						default:
							break;
					}
				}

				//Then comes data bytes
				else
				{
					switch(cmd)
					{
						//Readback commands do nothing here
						case 0x00:
						case FRONT_GET_STATUS:
						case FRONT_ERASE_APP:
							break;

						//Flash address (little endian)
						case FRONT_FLASH_ADDR:
							wraddrNext = (wraddrNext >> 8) | (data << 24);
							break;

						//Expected CRC32 (little endian)
						case FRONT_EXPECTED_CRC:
							expectedCRC = (expectedCRC >> 8) | (data << 24);
							break;

						//Flash data
						case FRONT_FLASH_WRITE:
							writebuf.Push(data);
							break;

						default:
							//g_log("Unrecognized command %02x\n", cmd);
							break;

					}
				}

				nbyte ++;
			}
		}
		*/
	}
}

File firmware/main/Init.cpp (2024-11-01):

/***********************************************************************************************************************
*                                                                                                                      *
* common-ibc                                                                                                           *
*                                                                                                                      *
* Copyright (c) 2024 Andrew D. Zonenberg and contributors                                                              *
* All rights reserved.                                                                                                 *
*                                                                                                                      *
* Redistribution and use in source and binary forms, with or without modification, are permitted provided that the     *
* following conditions are met:                                                                                        *
*                                                                                                                      *
*    * Redistributions of source code must retain the above copyright notice, this list of conditions, and the         *
*      following disclaimer.                                                                                           *
*                                                                                                                      *
*    * Redistributions in binary form must reproduce the above copyright notice, this list of conditions and the       *
*      following disclaimer in the documentation and/or other materials provided with the distribution.                *
*                                                                                                                      *
*    * Neither the name of the author nor the names of any contributors may be used to endorse or promote products     *
*      derived from this software without specific prior written permission.                                           *
*                                                                                                                      *
* THIS SOFTWARE IS PROVIDED BY THE AUTHORS "AS IS" AND ANY EXPRESS OR IMPLIED WARRANTIES, INCLUDING, BUT NOT LIMITED   *
* TO, THE IMPLIED WARRANTIES OF MERCHANTABILITY AND FITNESS FOR A PARTICULAR PURPOSE ARE DISCLAIMED. IN NO EVENT SHALL *
* THE AUTHORS BE HELD LIABLE FOR ANY DIRECT, INDIRECT, INCIDENTAL, SPECIAL, EXEMPLARY, OR CONSEQUENTIAL DAMAGES        *
* (INCLUDING, BUT NOT LIMITED TO, PROCUREMENT OF SUBSTITUTE GOODS OR SERVICES; LOSS OF USE, DATA, OR PROFITS; OR       *
* BUSINESS INTERRUPTION) HOWEVER CAUSED AND ON ANY THEORY OF LIABILITY, WHETHER IN CONTRACT, STRICT LIABILITY, OR TORT *
* (INCLUDING NEGLIGENCE OR OTHERWISE) ARISING IN ANY WAY OUT OF THE USE OF THIS SOFTWARE, EVEN IF ADVISED OF THE       *
* POSSIBILITY OF SUCH DAMAGE.                                                                                          *
*                                                                                                                      *
***********************************************************************************************************************/

/**
	@file
	@author	Andrew D. Zonenberg
	@brief	Boot-time hardware intialization
 */
#include "ibc.h"
#include "regids.h"
#include <math.h>
#include "OneHzTimerTask.h"
#include "TwoHzTimerTask.h"
#include "LocalConsoleTask.h"
#include "OutputEnableTask.h"

//Indicator LEDs
GPIOPin g_standbyLED(&GPIOB, 12, GPIOPin::MODE_OUTPUT, GPIOPin::SLEW_SLOW);
GPIOPin g_onLED(&GPIOB, 15, GPIOPin::MODE_OUTPUT, GPIOPin::SLEW_SLOW);
GPIOPin g_faultLED(&GPIOA, 8, GPIOPin::MODE_OUTPUT, GPIOPin::SLEW_SLOW);

//Output enables
GPIOPin g_outEnableFromLoad(&GPIOH, 0, GPIOPin::MODE_INPUT, GPIOPin::SLEW_SLOW);
GPIOPin g_outEnableFromProtection(&GPIOB, 10, GPIOPin::MODE_OUTPUT, GPIOPin::SLEW_SLOW);
GPIOPin g_loadEnableSense(&GPIOB, 7, GPIOPin::MODE_INPUT, GPIOPin::SLEW_SLOW);

//Hardware version straps
GPIOPin g_hwVersionStrap(&GPIOB, 0, GPIOPin::MODE_INPUT, GPIOPin::SLEW_SLOW);

//I2C2 defaults to running of APB clock (40 MHz)
//Prescale by 4 to get 10 MHz
//Divide by 100 after that to get 100 kHz
I2C g_i2c(&I2C2, 4, 100);

//The ADC (can't be initialized before InitClocks() so can't be a global object)
ADC* g_adc = nullptr;

///@brief Firmware version string
char g_version[20] = {0};

///@brief Software version string
char g_hwversion[20] = {0};

void ZeroizeOffsets();

//Offset voltage of the output current shunt
uint16_t g_outputCurrentShuntOffset = 0;
uint16_t g_inputCurrentShuntOffset = 0;

IBCI2CServer* g_i2cServer = nullptr;

////////////////////////////////////////////////////////////////////////////////////////////////////////////////////////
// Peripheral initialization

void App_Init()
{
	//Turn off the output
	g_outEnableFromProtection = 0;

	RCCHelper::Enable(&_RTC);
	InitGPIOs();
	InitI2C();
	InitADC();

	//Format version string
	StringBuffer buf(g_version, sizeof(g_version));
	static const char* buildtime = __TIME__;
	buf.Printf("%s %c%c%c%c%c%c",
		__DATE__, buildtime[0], buildtime[1], buildtime[3], buildtime[4], buildtime[6], buildtime[7]);
	g_log("Firmware version %s\n", g_version);

	//Format hardware version string
	StringBuffer hbuf(g_hwversion, sizeof(g_hwversion));
	if(g_hwVersionStrap)
		hbuf.Printf("0.5");
	else
		hbuf.Printf("0.4");
	g_log("Hardware version %s\n", g_hwversion);

	//Turn on our internal output enable (TODO: check protections)
	g_outEnableFromProtection = 1;

	g_log("Init complete, output turned off until start requested by host board\n");

	//Initialize the local console
	static LocalConsoleTask localConsoleTask;
	g_tasks.push_back(&localConsoleTask);

	//10 kHz ticks so 10K ticks = 1 sec
	static OneHzTimerTask timerTask(0, 10 * 1000);
	g_tasks.push_back(&timerTask);
	g_timerTasks.push_back(&timerTask);

	//10 kHz ticks so 5K ticks = 0.5s
	static TwoHzTimerTask timerTask2(0, 10 * 500);
	g_tasks.push_back(&timerTask2);
	g_timerTasks.push_back(&timerTask2);

	//Output enable LEDs etc
	static OutputEnableTask oeTask;
	g_tasks.push_back(&oeTask);
}

////////////////////////////////////////////////////////////////////////////////////////////////////////////////////////
// Other hardware init

void InitGPIOs()
{
	g_log("Initializing GPIOs\n");

	//Version strap pins default low unless explicitly set high
	g_hwVersionStrap.SetPullMode(GPIOPin::PULL_DOWN);

	g_standbyLED = 1;
	g_faultLED = 0;
	g_onLED = 0;
}
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

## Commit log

2024-07-04 Initial IBC schematic passes ERC
    [common-ibc.kicad_pcb, common-ibc.kicad_sch]
2024-07-05 Most of the way done with layout
    [common-ibc.kicad_pcb, common-ibc.kicad_sch]
2024-07-06 Finished initial layout of IBC, ready for final review
    [common-ibc.kicad_pcb, common-ibc.kicad_sch]
2024-07-06 Minor silkscreen tweaks
    [common-ibc.kicad_pcb]
2024-07-06 Finished layout review on IBC, made some tweaks to routing and solder paste
    [common-ibc.kicad_pcb, common-ibc.kicad_sch]
2024-07-06 Enlarged fuse holder annular ring
    [common-ibc.kicad_pcb]
2024-07-08 Final version sent to fab for quotes
    [common-ibc.kicad_pcb]
2024-07-08 Added gerber viewer project
2024-08-04 Initial IBC bootloader
    [common-ibc.kicad_sch, dongle.cfg]
2024-08-05 Now at minimum functional state with no I2C management support
    [common-ibc.kicad_sch]
2024-08-09 Initial I2C server class implementation
    [common-ibc.kicad_sch]
2024-08-09 Continued initial I2C server implementation
2024-08-10 Hopefully-mostly-done v0.5 layout
    [common-ibc.kicad_pcb, common-ibc.kicad_sch]
2024-08-10 Updated readme to describe new protection circuitry
2024-08-10 Request UL mark on front of PCB now
    [common-ibc.kicad_pcb]
2024-08-10 IBC now reports input and output current via I2C properly
2024-08-11 Added I2C registers for MCU version, hardware version, MCU temperature, and 3V3_SB rail voltage
2024-08-11 Added offset calibration coefficients stored in flash for both of the current shunt amplifiers
2024-08-12 Final v0.5 IBC design going to fab for quotes
    [common-ibc.kicad_pcb, common-ibc.kicad_sch]
2024-08-17 Converted over to CMake build flow, removed legacy makefiles
2024-08-23 Updated for latest libraries and enabled trace in debug builds
2024-09-08 Fixed typo in error message
    [Init.cpp]
2024-09-08 Added "output forceon" and "output normal" commands for load testing without a host board
2024-11-01 Initial refactoring to task model
    [common-ibc.kicad_sch]
